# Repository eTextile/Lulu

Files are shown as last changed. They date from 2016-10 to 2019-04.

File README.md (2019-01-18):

# Lulu-star

**Programming light into textile**

Lulu is a hardware solution that interfaces between an LED light source, an optic fiber strand or bundle and soft circuit connections.
Providing an optic fiber connection toolset and workflow for E-Textiles and Wearable Technology applications.

This project is still in a beta phase, where drastic changes may occur and backwards compatibility is not guaranteed until the final release.

Lulu-star
Lulu-star
Lulu-star

### About The project
Lulu is providing a simple, reliable toolset for people who want to use side glow optical fibers in their eTextile and wearable projects.
Use of light in textile and fashion design is becoming more and more common and many schools started to teach this subject as a part of their textile design curriculum.
Optic fibers could be embedded in textiles as embroidery, in weaving, knitting and knotting process and many textile designs have been realized in recent years.
But often the designers lack the toolset for connecting the light sources with the embedded optic fibers, resulting in re-purposing bulky connectors and technology and hiding them behind the textiles.
Currently, each designer has to come up with their own re-purposed or DIY solution.
Lulu is a connector that optimizes the efficiency of the connection between the light source and the optical fibers to get a strong illumination.
Instead of struggling to solve the light source and connection problem, the designer can concentrate on the aesthetic and textile making process issues.

### Lulu branches
- **Lulu-star** (master)
  - This branch provide a tiny PCB with a 200mA LED, PWM driver and optic fiber connector.
- **Lulu-daisy**
  - This branch provide a tiny PCB with an addressable LED (WS2812-mini, Dotstar, etc) and an optic fiber connector.
- **Lulu-MCU**
  - This branch provide a tiny PCB with a built in MCU (ATTiny10) that allow one-wire communication bus system.
- **Lulu**
  - This branch provides a motherboard (Lucette) that drives up to 16 Lulus that each only contain a power LED and an optic fiber connector.

###  Branche naming conventions / Version Control
- First number is used to specify Lulu type
  - 2.0.0 -> Lulu-star
  - 3.0.0 -> Lulu-daisy
  - 4.0.0 -> Lulu-MCU
- Second number is used to specify the PCB shape
  - 2.0.0 -> Lulu-star/Circle (this is the most common eTextile PCB shape but doesn't fit the zero waste).
  - 2.1.0 -> Lulu-star/Triangle (this shape fit the three wire connectors and zero waste panelization process).
  - 2.2.0 -> Lulu-star/Blob...
- Third number is used to specify the iteration
  - 2.1.1 -> [Made with Upverter an online PCB router software.](https://upverter.com/DataPaulette/08fe1452dfd87b08/Lulu-star_211/ "Made with Upvetrter, online PCB router software") 
  - 2.1.2 -> [Made with KiCad 5.0.0](./kicad_Lulu_star/Lulu_star_212/ "Made with KiCad 5.0.0") 

### Development tools & DOCs
 * **Web page**: [http://lulu.eTextile.org](http://lulu.eTextile.org "The project Web page")
 * **Kobakant web page**: [http://www.kobakant.at/KOBA/lulu-developments](http://www.kobakant.at/KOBA/lulu-developments "Kobakant project Web page")
 * **Repository**: [https://github.com/eTextile/Lulu/tree/master](https://github.com/eTextile/Lulu/tree/master "The project repository")
 * **License**: [CC-BY-SA](https://github.com/eTextile/Lulu/blob/master/LICENSE "See the Lulu license project")
 * **Video**: [Lulu project by Hannah](https://www.youtube.com/watch?v=drAoLd_eUWk "Lulu project Introduction")
 * **Video**: [Lulu project by Maurin](https://vimeo.com/249171264 "eTextile bus solution")
 * **Mail**: [lulu@etextile.org](mailto:lulu@etextile.org "eMail us")
 * **IRC**: [Riot](https://vector.im/develop/#/room/#lulu:matrix.org "Join us on the chat to collaborate in the development")
 * **Pictures**: [Flickr](https://www.flickr.com/groups/3908991@N25/ "Share your Lulu pictures project")

```
*Editable / multipurpose
                                 Forkable
             Low|-------------------|//////////////////////////////////////////|High

*Production method
                            Crafter
             DIY|--------------|///////////////////////////////////////////////|Industry

*Price
                                             6€
             Low|////////////////////////////|---------------------------------|High

*Skils level of users
                                                 Crafter
        Beginers|///////////////////////////////////|--------------------------|Expert

*Level of integration
               PCB                   PCB++
        Standard|/////////////////////|----------------------------------------|Non standard (e-textile)

*Level of complexity
                                                                          Lulu + LED-driver
                                                           Lulu + LED-driver   + MCU
              Lulu               Lulu + LED-driver         Lulu + MCU          + Battery & charger
             Low|/////////////////////| ------------------------|--------------|High

*Robusness / Life span (Connectors, testing, evaluating)
         Fragile|/////////////////////| ------------------------|--------------|Stong

*Project ethics
                                                         Sparkfun
              DIY  Crow-fonded  Localy                   Adafruit  Seed      China
           High|--------|--------|//////////////////////////|--------|---------|low

*Optic Fibers
               20cm    1m     2m
           Schot|------|///////|-----------------------------------------------|Long

*Tech
                                                OpenPCB                  Open-cylycium
          Closed|-------------------------|////////|///////|-------------------|Free & Full Open

*Liscence
          Closed|--------------------------------------------------------------|Free & Open

*Peripherals
     Free (Open)|-------------------|-----------------------|------------------|Closed

```

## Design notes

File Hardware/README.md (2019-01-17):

# Lulu-star / Hardware
**Programming light into textile**

# Lulu-star

Lulu_212_KiCad-3D_recto
Lulu_212_KiCad-3D_verso

## Hardware design
This branch of the Lulu project is using a 200mA power LED with current current circuitry.
As the project is focussing on embedded electronics we chosed an high power OSRAM OSLON LED that can have a good autonomy with a small Lypo battry (1000 mA).
As this kind of LED is seeking 200 mA (5 hour of autonomy with a 1000 mA battery).
The LED is also providing a narrow angle (60°) to focus the light in the optic fiber tranche.
	See datasheet: https://github.com/eTextile/Lulu/blob/master/Hardware/DOCs/LY_CN5M.pdf
The brass tube connector have been selected to fit the outer diameter of the LED package.
The PCB triangle shape have been selected to fit the zero waste in the production process.
All the components are SMD package to reduce the size and price of th PCB.
We have been experiencing a new way to hand solder the LED on the edge of the PCB but it is still not so handy to do it manually.
Custom tooling will be designed and tested to help in that soldering process.

## Release notes
### Lulu-star 2.1.2
- Initial release
### Lulu-star 2.1.3
- Clearance of top and bottom ground plane have been increased to avoid shortcuts due to the board edge cut to close.
- Resistor R2 have been flipped and the brass tube soldering pad moved.
- Updated brass tube soldering pad to be connected to the ground plane with thermals.
- Increased size of sewing holes to : 2mm
- Increased size of eTextile connectors to : 1mm
- Increased board size by ... mm
- Reorganized eTextile connectors order, this is more convenient for many purposes.

## Lulu connecting
- [VCC] (+) 3.3 to 5 Voltes
- [GND] (-) GND
- [PWM] I/O PIN

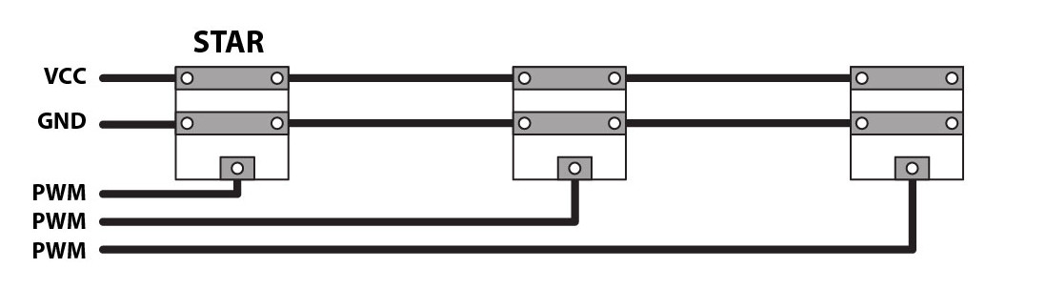
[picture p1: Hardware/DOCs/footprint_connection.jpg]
Footprint_connection


        +---+--------------+-------------------+-----
        |   |              |                   |
    + __|__ |              |                   |
    -  ___  |              |                   |
        |   |              |                   |
        +---|--------------|--+----------------|--+--
        |   |              |  |                |  |
        |   |              |  |                |  |
        |   |            __|__|__              |  |
       _|___|_           \ +  - /              |  |
      | +   - |           \    /               |  |
      |   M   |--- PWM --> \  /              __|__|__
      |   C   |             \/               \ +  - /
      |   U   |                               \    /
      |       |--- PWM ----------------------> \  /
      |_______|                                 \/

## Lulu-star Powering
The Lulu board must be powered with a voltage betwin 3.3V to 5V.
DO NOT USE 3V single coin battery - voltage is too low and it will not work for long.
Prefer the use of rechargeable Lipo battery with small Lipo charger.

## Lulu-star Arduino programming
Easy to programmed, Lulu-star is using the Arduino IDE standard functions - no library required.

    digitalWrite(LED_PIN, state);
    analogWrite(LED_PIN, val);

## Lulu-star LED driver built-in
### Constant current source circuitry

**References**
- https://learn.adafruit.com/pixie-3-watt-smart-chainable-led-pixels/design
- http://www.instructables.com/id/Power-LED-s---simplest-light-with-constant-current/
- https://scienceprog.com/building-simple-constant-current-power-led-driver/
- http://www.pcbheaven.com/userpages/LED_driving_and_controlling_methods/?topic=worklog&p=3

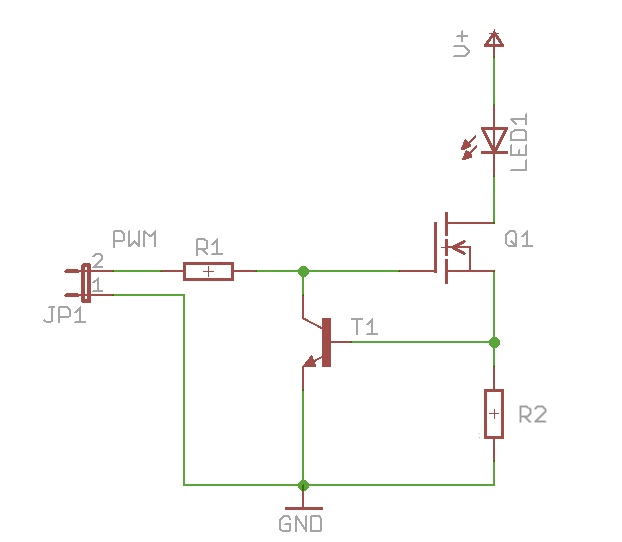
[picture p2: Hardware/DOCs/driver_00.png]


### Circuit part list
| Designator | MPN | Package | Price per unit | Weblink |
| --- | --- | ---|--- |---|
| Power LED / OSRAM 200mA | LY CN5M | | 0.65 $ | [LY-CN5M](https://fr.aliexpress.com/item/OSRAM-OSLON-SX-High-Power-LED-0-5W-3030-Yellow-LY-CN5M/32865040281.html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) |
| Q1 - large N-channel MOSFET | IRLML2060TRPBF | SOT-23 | 0,126 € | [IRLML2060TRPBF](https://www.digikey.com/product-detail/en/infineon-technologies/IRLML2060TRPBF/IRLML2060TRPBFCT-ND/2271917) |
| T1 - small NPN transistor | MMBT2222A | SOT-23 | 0,0412 € | [MMBT2222A](https://www.digikey.com/product-detail/en/diodes-incorporated/MMBT2222A-7-F/MMBT2222A-FDICT-ND/815723) |
| R1 - 47k-ohm resistor | RT0603DRD0747KL | 0603 | 0,0147 € | [R-47k-ohm ](https://www.digikey.com/product-detail/en/yageo/RT0603DRD0747KL/311-47KDCT-ND/1035828) |
| R2 - current set resistor - 2.7 ohms 1/4 watt | | 1206 | 0,0246 € | [R-2.7-ohm](https://fr.farnell.com/walsin/wr12w2r70ftl/resist-couche-epaisse-2-7r-1-0/dp/2668305) |
| R3 - 10k pull-down resistor | RT0603DRD0710KL | 0603 | 0, € | [R-10k-ohm](https://www.digikey.com/product-detail/en/yageo/RT0603DRD0710KL/311-10KDCT-ND/1035680) |

**R2** is used to set the current limit and this doesn't depends on the voltage supply VDD.
**Q1** is used as a variable resistor. **Q1** starts out turned on by **R1**.
**T1** is used as an over-current sensing switch, and **R2** is the "sense resistor" that triggers **T1** when too much current is flowing.
The main current flow is through the LED's, through **Q1**, and through **R2**.
When too much current flows through **R2**, **T1** will start to turn on, which starts turning off **Q1**. Turning off **Q1** reduces the current through the LED's and **R2**.
So we've created a **feedback loop**, which continuously tracks the current and keeps it exactly at the set point at all times.
The NPN transistors **T1** have a specified 0.6V drop between base and emitter when on.
This means the voltage across their respective shunt resistors **R2** will always be 0.6V.
According to Ohm’s law, this means that the current through them will be '0.6 V / 2.7 Ohm', or about 222mA.

## PCB manufacturing characteristics
  - Base Material : FR-4 TG13
  - No. of Layers : 2 layers
  - PCB Thickness : 1 mm
  - PCB Color : Yelow
  - Surface Finish : HASL
  - Minimum Solder Mask Dam : 0.4 mm
  - Copper Weight : 1oz (35 µm)
    - For 300 mA we nead 0.15mm copper traces (https://www.4pcb.com/trace-width-calculator.html)
  - Minimum Drill Hole Size : 0.3 mm
  - Trace Width / Spacing : 5/5 mil
  - Blind or Buried Vias : NO
  - Plated Half-holes / Castellated Holes : YES
  - Impedance Control : NO

### Extra Part list
| Part | REF | Price per unit | Weblink |
| --- | --- | ---|--- |
| Brass tube | 2 mm Hole 5-10 mm Length | | |
| JTE connector | 1.5 / 8 mm | | |
| Optical fibres PMMA | 0.25 mm x 35 pce | | |
| Optical fibres TPU | 1.5, 2, 3 mm | | |
| Optical fibres tube + core | | | [www.leds-and-more.de](https://www.leds-and-more.de/catalog/15mm-lwl-lichtwellenleiter-lichtleiter-seitlich-leuchtend-p-1937.html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) |

## TODO
- [ ] Find 0.5W side LEDs
- [ ] Chose between a small single LED driver & Constant current source circuitry
- [ ] Optimize the power LED heat dissipation
- [ ] Identifying distributors in Europe

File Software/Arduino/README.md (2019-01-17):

# Lulu-star

### Programming light into textile
This file is listing a group of examples that can be a starting point to make a project out of the Lulu-star hardware.

Microcontroleurs such as Adafruit Gemma, Trinketor or DIGISPERK are cool components to get a nice eTextile integration.

## DIGISPARK specifications

** UNDER MACKINTOSH YOU WILL NEED A USB HUB TO PROGRAM THE DIGISPARK BOARD! **
- Instaling Digispark support for Arduino
  - Add this link to the Arduino Préférences : http://digistump.com/package_digistump_index.json
  - Look for Digispark into the Arduino bord manager

    Digispark digital I/O PINs
    - Pin 0 → I2C SDA, PWM (LED_BUILTIND on Model B)
    - Pin 1 → PWM (LED_BUILTIN on Model A)
    - Pin 2 → I2C SCK, Analog
    - Pin 3 → Analog In (also used for USB+ when USB is in use)
    - Pin 4 → PWM, Analog (also used for USB- when USB is in use)
    - Pin 5 → Analog In

## Adafruit Gemma specifications

- Instaling Gemma support for Arduino
  - Add this link to the Arduino Préférences : https://adafruit.github.io/arduino-board-index/package_adafruit_index.json
  - Look for Gemma into the Arduino bord manager

** THE SKETCH UPLOADING PROCESS IS NOT AS STANDARD ARDUINO BOARD **
...

#### Lulu_blink
Blinking a single lulu board

#### Lulu_fade
Fading a single lulu board (FIXME)

#### Lulu_fade_with_sensor
Fading the Lulu in combination with a light sensor (TODO)

#### Lulu_...

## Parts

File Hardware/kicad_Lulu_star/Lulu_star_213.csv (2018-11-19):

Designator | MPN | Qty | Link
R3 | RT0603DRD0710KL | 1 | https://www.digikey.com/product-detail/en/yageo/RT0603DRD0710KL/311-10KDCT-ND/1035680
T1 | MMBT2222A | 1 | https://www.digikey.com/product-detail/en/diodes-incorporated/MMBT2222A-7-F/MMBT2222A-FDICT-ND/815723
Q1 | IRLML2060TRPBF | 1 | https://www.digikey.com/product-detail/en/infineon-technologies/IRLML2060TRPBF/IRLML2060TRPBFCT-ND/2271917
R1 | RT0603DRD0747KL | 1 | https://www.digikey.com/product-detail/en/yageo/RT0603DRD0747KL/311-47KDCT-ND/1035828

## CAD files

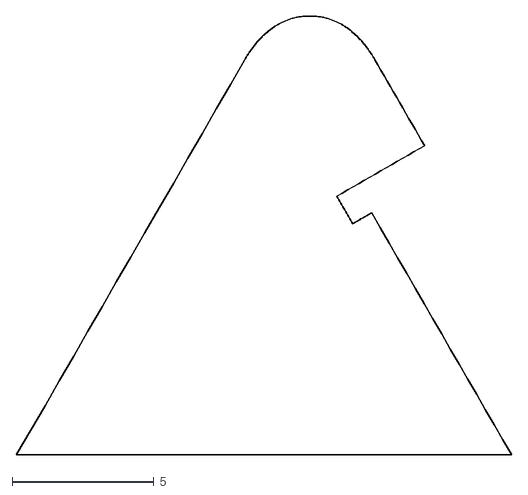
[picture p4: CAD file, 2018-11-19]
Hardware/kicad_Lulu_star/edge_path/Lulu_PCB_path_03.dxf
17.5 x 15.5

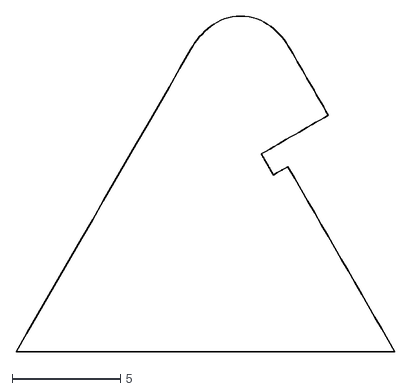
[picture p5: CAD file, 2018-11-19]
Hardware/kicad_Lulu_star/edge_path/Lulu_PCB_path_02.dxf
17.5 x 15.5

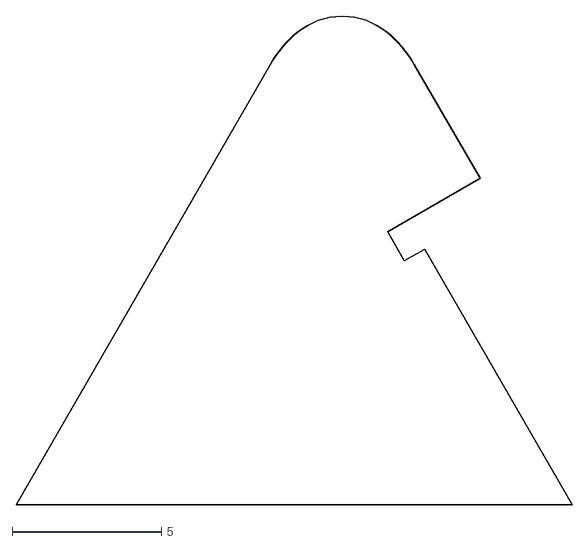
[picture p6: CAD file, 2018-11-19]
Hardware/kicad_Lulu_star/edge_path/Lulu_PCB_path_04.dxf
18.6 x 16.3

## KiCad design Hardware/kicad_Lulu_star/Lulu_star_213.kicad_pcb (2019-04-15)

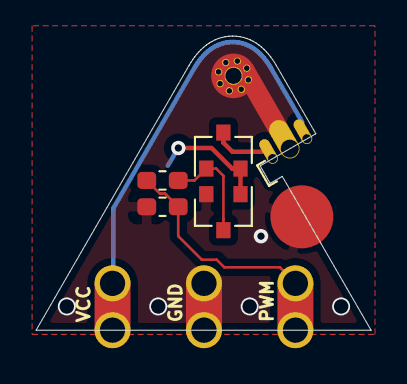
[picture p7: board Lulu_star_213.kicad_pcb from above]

Board: 2 copper layers, 18.6 x 16.3 mm, 9 parts (1 on the bottom side), 6 nets.

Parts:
J1: Conn_01x03_Female; Lulu_plug_3_spaced
LED1: LED_PAD; Lulu_side_LED
P1, P1#2: Soldering_pad; Lulu_brass_tube_pad
Q1: Q_NMOS_GSD; SOT-23
R1: 47K; R_0603_1608Metric_Pad1.05x0.95mm_HandSolder
R2: 2.7 Ohm; R_1206_3216Metric_Pad1.42x1.75mm_HandSolder
R3: 10K; R_0603_1608Metric_Pad1.05x0.95mm_HandSolder
T1: Q_NPN_BEC; SOT-23

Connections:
+3V3: J1.1, LED1.2
/PWM: J1.3, R1.2, R3.1
GND: J1.2, LED1.3, R2.2, R3.2, T1.2
unnamed: LED1.1, Q1.3
unnamed: Q1.1, R1.1, T1.3
unnamed: Q1.2, R2.1, T1.1

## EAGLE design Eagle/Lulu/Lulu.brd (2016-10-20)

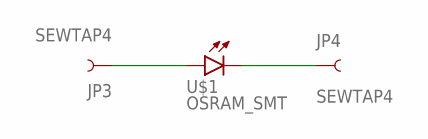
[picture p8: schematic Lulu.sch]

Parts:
JP3, JP4: SEWTAP4; PETAL-SMALL
U$1: OSRAM_SMT; OSLON

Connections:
unnamed: JP3.1, U$1.A
unnamed: JP4.1, U$1.C

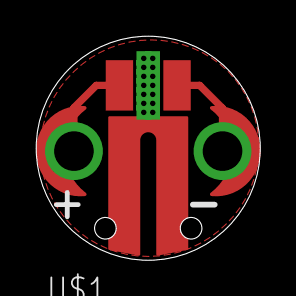
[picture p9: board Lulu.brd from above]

Board: 2 copper layers, 12.4 x 12.4 mm, 3 parts (0 on the bottom side), 2 nets.

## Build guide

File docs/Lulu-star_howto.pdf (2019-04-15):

# Lulu-star V2.2.1

## Exploring light through textile

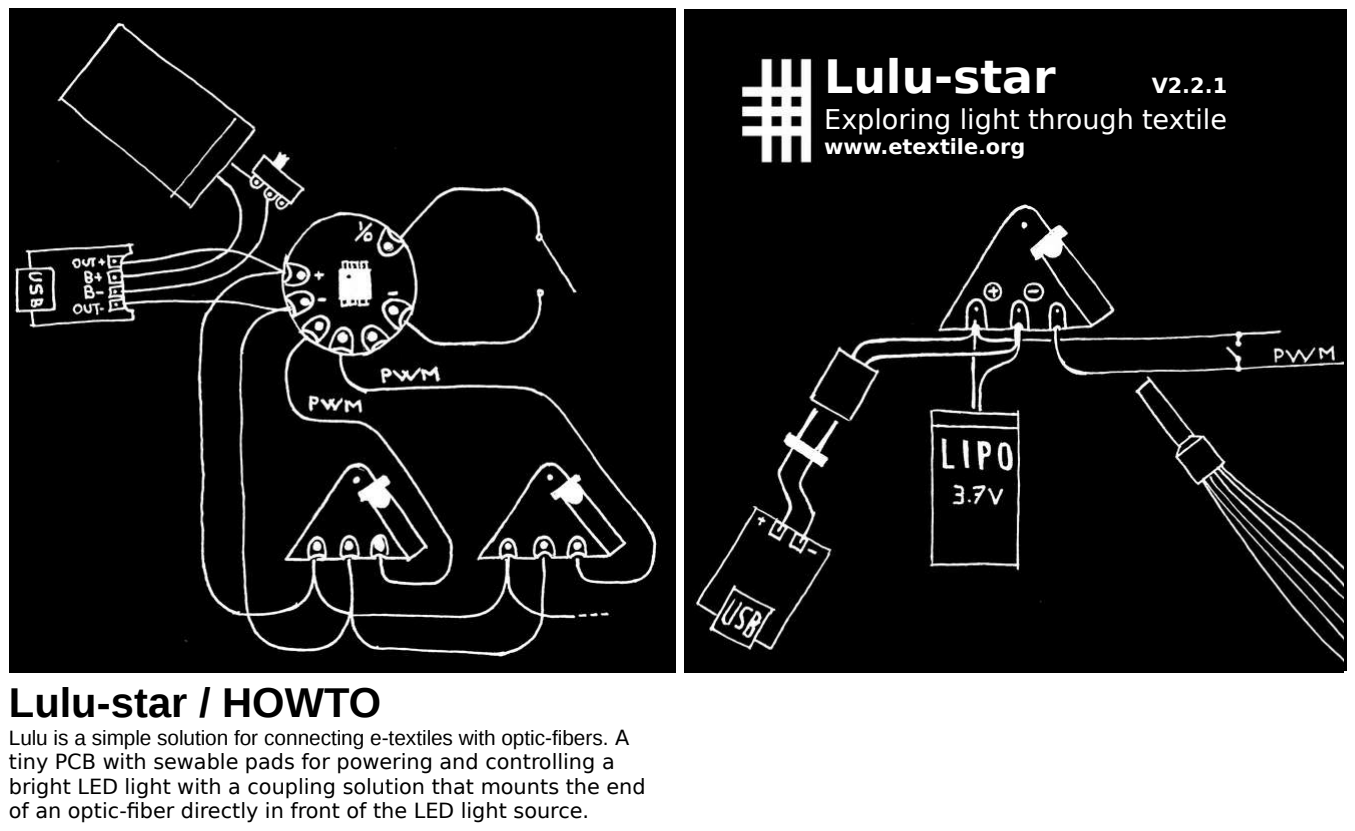
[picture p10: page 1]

www.etextile.org

# Lulu-star / HOWTO

Lulu is a simple solution for connecting e-textiles with optic-fibers. A tiny PCB with sewable pads for powering and controlling a bright LED light with a coupling solution that mounts the end of an optic-fiber directly in front of the LED light source.

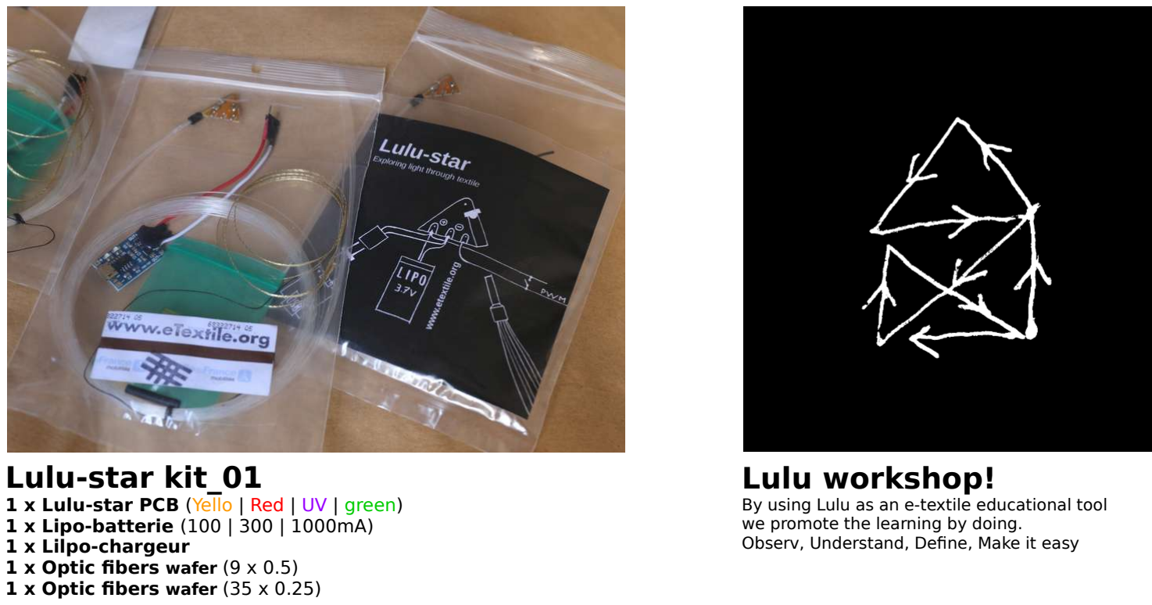
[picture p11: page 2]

L

## ulu-s

t

a

r

V

2.2.1

# Lulu workshop!

By using Lulu as an e-textile educational tool we promote the learning by doing.
Observ, Understand, Define, Make it easy

# Lulu-star kit_01

### 1 x Lulu-star PCB (Yello | Red | UV | green) 1 x Lipo-batterie (100 | 300 | 1000mA) 1 x Lilpo-chargeur 1 x Optic fibers wafer (9 x 0.5) 1 x Optic fibers wafer (35 x 0.25)

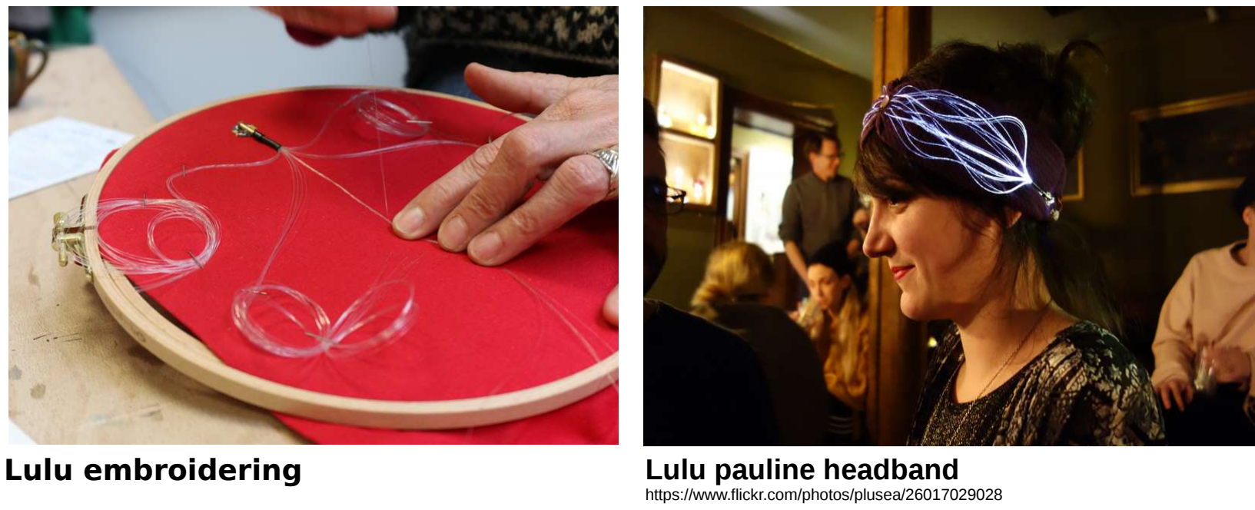
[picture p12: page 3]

L

## ulu-s

t

a

r

V

2.2.1

Lulu embroidering | Lulu pauline headband https://www.flickr.com/photos/plusea/26017029028

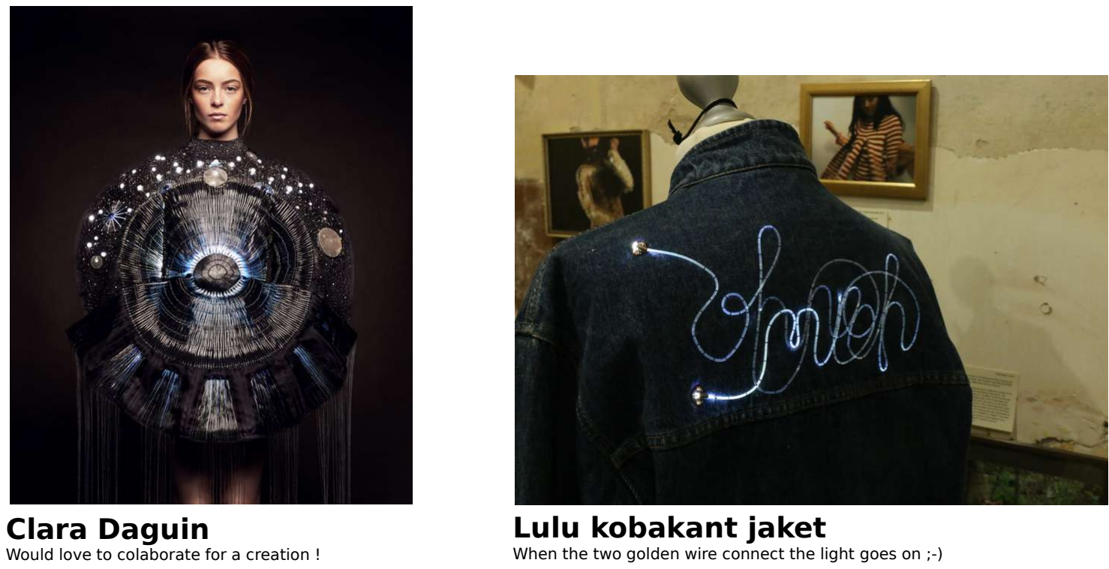
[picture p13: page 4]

L

## ulu-s

t

a

r

V

2.2.1

# Lulu kobakant jaket

When the two golden wire connect the light goes on ;-)

# Clara Daguin

Would love to colaborate for a creation !

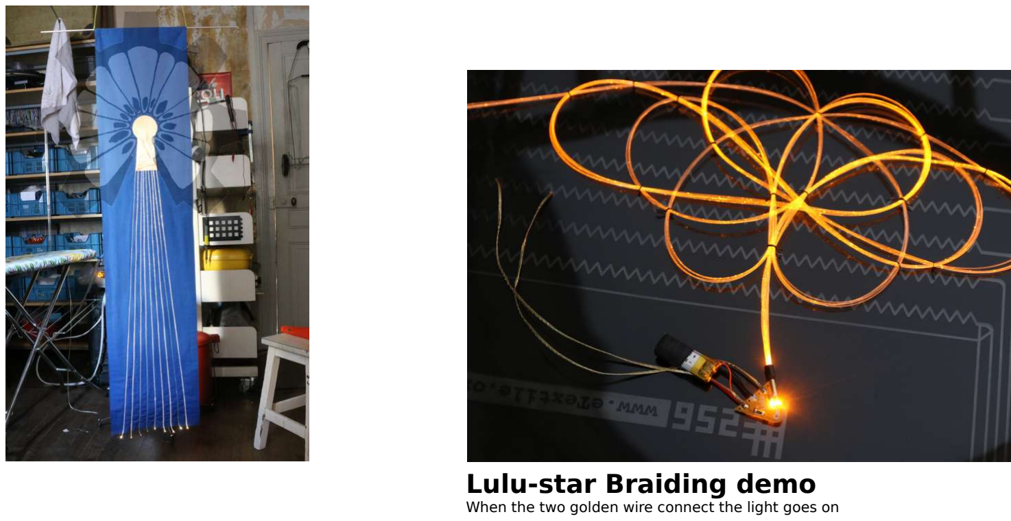
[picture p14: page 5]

L

## ulu-s

t

a

r

V

2.2.1

# Lulu-star Braiding demo

When the two golden wire connect the light goes on

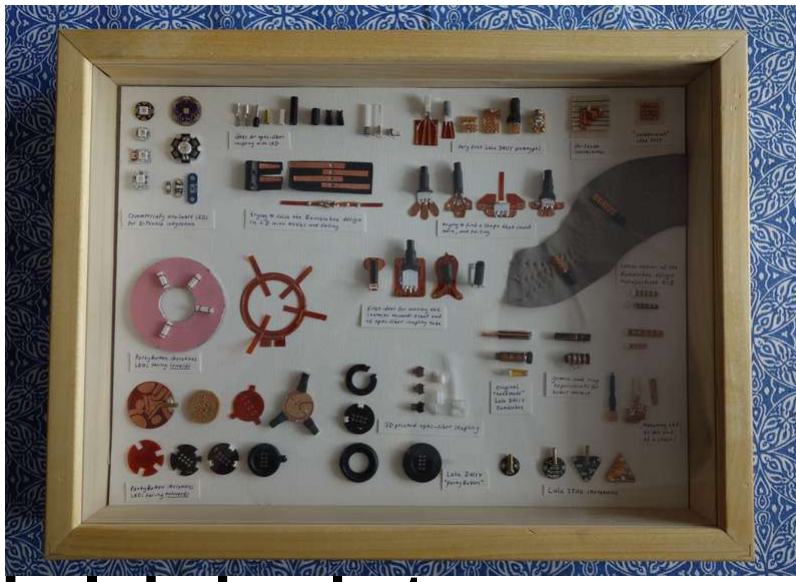
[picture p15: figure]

# Lulu’s backstage

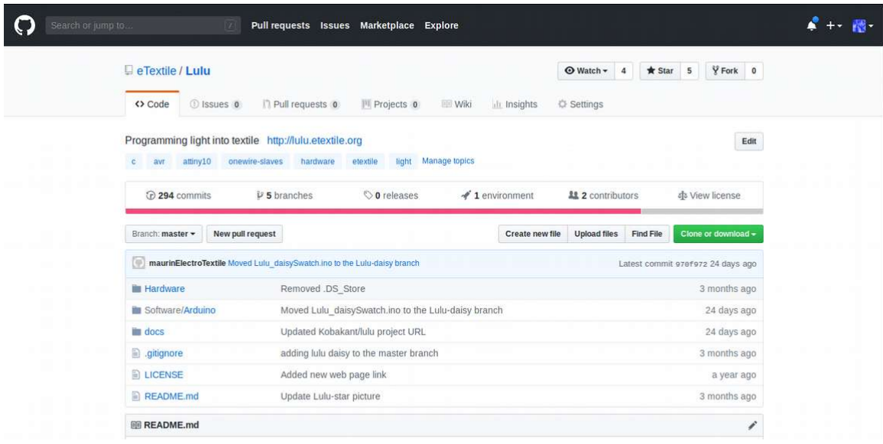
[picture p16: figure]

# Open hardware & open software

The project source code is hosted on Github repository Users can fork the design to adapt to their needs
and collaborate in the development.

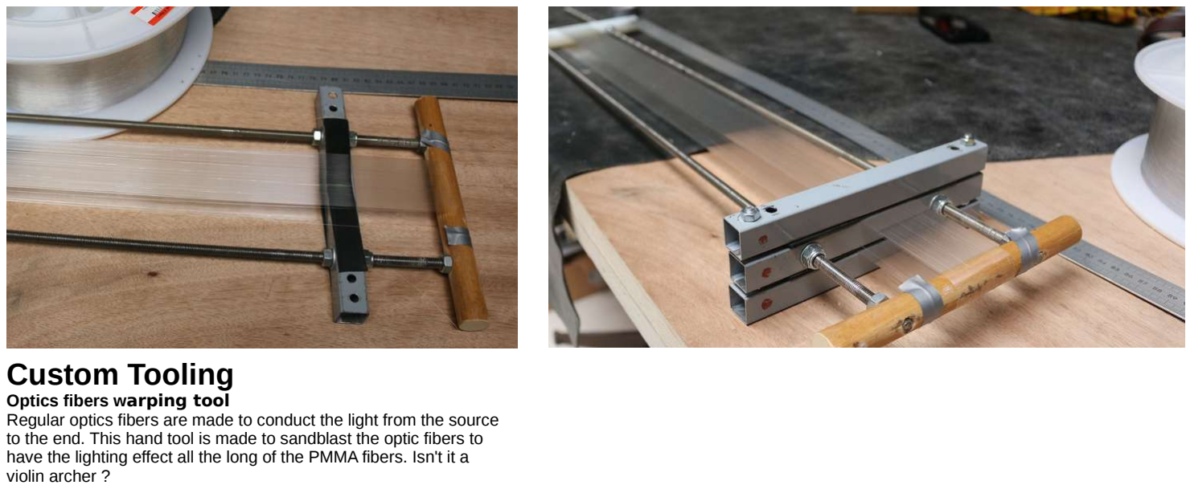
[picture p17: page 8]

# Custom Tooling

Optics fibers warping tool
Regular optics fibers are made to conduct the light from the source to the end. This hand tool is made to sandblast the optic fibers to have the lighting effect all the long of the PMMA fibers. Isn't it a violin archer ?

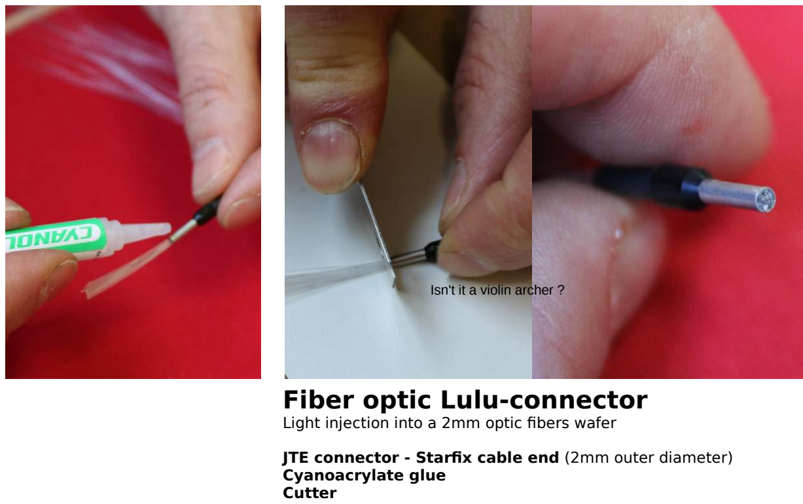
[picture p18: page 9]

# Fiber optic Lulu-connector

Light injection into a 2mm optic fibers wafer

JTE connector - Starfix cable end (2mm outer diameter) Cyanoacrylate glue
Cutter

Isn't it a violin archer ?

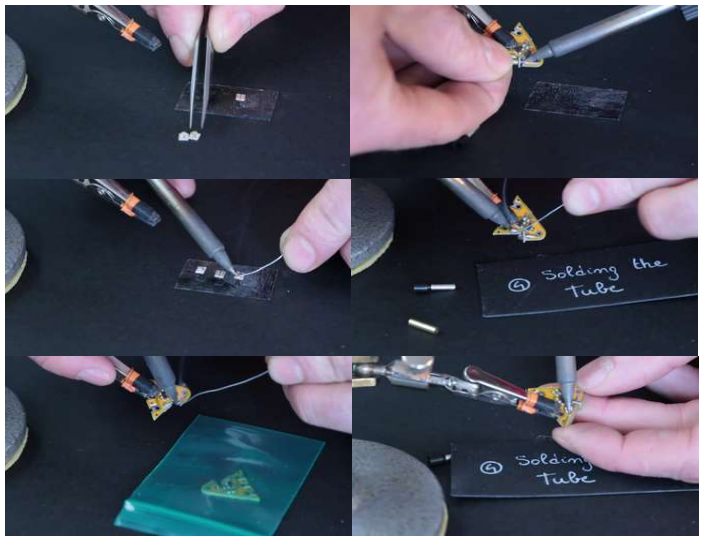
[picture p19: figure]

1/ LED tining
2/ PCB thermal pad tining
3/ LED Soldering
4/ Brass tube soldering (This can be optimized in the next Lulu-star version) 5/(R2) Resistor soldering (This curent setup resistor could be pick and place for 200mA setup, can still be resolder for other setup)

LED osram
oslon | Ref | Current | Résistor
YELOW (https://fr.farnell.com/osram/lhcp7p-2t3t-1/led-oslon-ssl-hyper-rouge-80/dp/2115537?ost=2115537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) | farnell.com /osram (https://fr.farnell.com/osram-opto-semiconductors/lacn5m-fbgb-24-1/led-oslon-sx-ambre/dp/1826990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) | 200 mA | 2.7 Ohm
RED (https://fr.farnell.com/osram/lhcp7p-2t3t-1/led-oslon-ssl-hyper-rouge-80/dp/2115537?ost=2115537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) | farnell.com /osram (https://fr.farnell.com/osram/lhcp7p-2t3t-1/led-oslon-ssl-hyper-rouge-80/dp/2115537?ost=2115537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) | 350 mA

GREEN

UV (https://fr.farnell.com/osram/lhcp7p-2t3t-1/led-oslon-ssl-hyper-rouge-80/dp/2115537?ost=2115537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)

# Lulu-star hand soldering

https://github.com/eTextile/Lulu/tree/master/Hardware Osram OSLON LED (200-350mA)
Brass tube (10mm long, 2mm inner diameter)
Current limit resistor R2 (Thick film 0.25W)

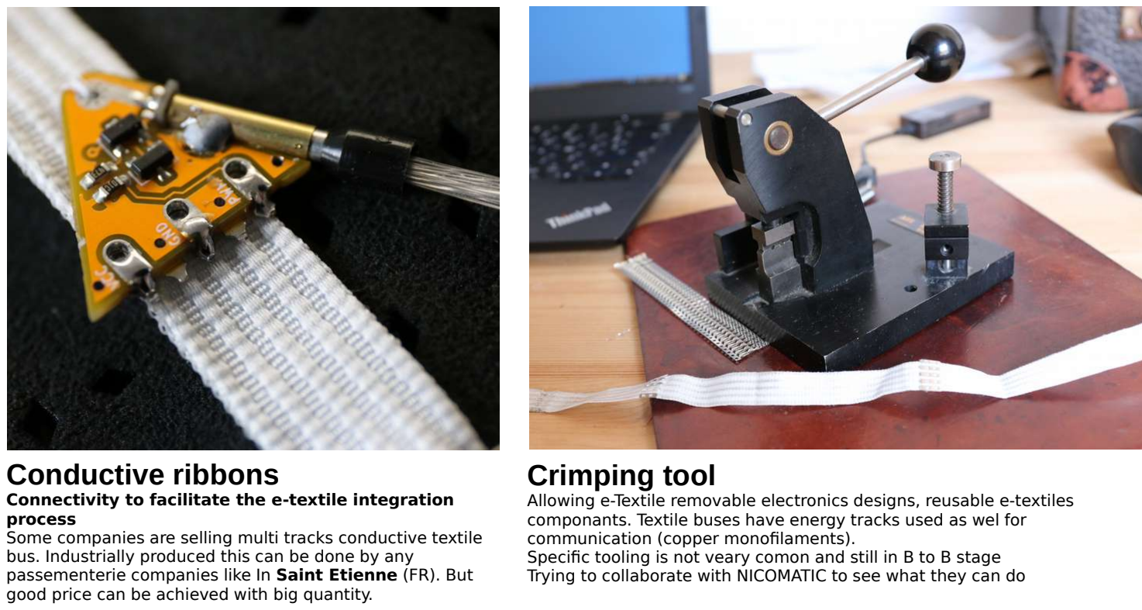
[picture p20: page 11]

# Crimping tool

Allowing e-Textile removable electronics designs, reusable e-textiles componants. Textile buses have energy tracks used as wel for communication (copper monofilaments).
Specific tooling is not veary comon and still in B to B stage
Trying to collaborate with NICOMATIC to see what they can do

# Conductive ribbons

Connectivity to facilitate the e-textile integration process
Some companies are selling multi tracks conductive textile bus. Industrially produced this can be done by any passementerie companies like In Saint Etienne (FR). But good price can be achieved with big quantity.

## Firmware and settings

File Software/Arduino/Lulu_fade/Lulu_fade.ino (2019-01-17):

/*
  Lulu - Programing light into textile

  Lulu-star / Arduino code / This sketch is an example that control a single Lulu.

  Lulu-star circuitry
     _________________________________
    |              |                  |
    |            __|__                |
    | +         |  +  |              / \
  __|__         |  M  |             / L \
   ---          |  C  |--- PWM --> /  U  \
    | -         |  U  |           /   L   \
    |           |__-__|          /____U____\
    |              |                  |
    |______________|__________________|

   (+) is 3.3 to 5V

*/
#include <elapsedMillis.h> // https://github.com/pfeerick/elapsedMillis

elapsedMillis timer;

const int PWM_PIN = 13; // This PIN is also connected to the Digispark Motherboard LED_BUILTIN.

void setup() {
  Serial.begin(9600);
  pinMode(PWM_PIN, OUTPUT);    // Set PIN as OUTPUT PIN
  digitalWrite(PWM_PIN, LOW);  // Set PIN LOW (GND)
}

void loop() {
  Serial.println(timer);
  // arg-0 the PWM pin
  // arg-1 the fade IN time
  // arg-1 the fade OUT time
  lulu_fade(13, 1000, 1000);
}

///////////////////////////////////// Fonction
// TODO adding timer as argument
void lulu_fade(uint8_t pwmPin, uint32_t fadeSpeedUp, uint32_t fadeSpeedDown) {
  static int pwmValue = 0;
  static int intervalUp = (int)(fadeSpeedUp / 255);
  static int intervalDown = (int)(fadeSpeedDown / 255);
  static boolean dir = true;

  // Fade In
  if (dir == true && timer > intervalUp) {
    timer = 0;
    analogWrite(pwmPin, pwmValue);
    pwmValue++;
    if (pwmValue >= 255) {
      dir = false;
    }
  }

  // Fade Out
  if (dir == false && timer > intervalDown) {
    timer = 0;
    analogWrite(pwmPin, pwmValue);
    pwmValue--;
    if (pwmValue <= 0) {
      dir = true;
    }
  }

}

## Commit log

2014-05-06 Update lucette_seq.ino
    Optimisation du protocole de communication entre la carte Lucette et un logiciel Pilote réalisé avec PureData. Pour contrôler une sortie de la carte Lucette il faut utiliser trois octets :
    le premier pour définir la LED à actualiser le second et le troisième pour définir la valeur 12 bits (0-4095) qui correspond à l'intensité de la LED.
2014-05-06 Update README.md
    Fonctions de la carte Lucette / fork du projet Arduino
2014-05-07 Create LEDs_seq
2014-05-17 Update Lucette_seq.ino
    Bug fix in ledUpdate();
2014-07-01 Update Lucette_seq.ino
    add ERROR Handling if a LED is diconnected.
2015-10-08 added eagle boards
    [LOGO.dxf, Lucette_LED.sch, Lucette_V05.brd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]
2016-10-19 Updated text
    Luce is the project, Lucette is the electronic board
2016-10-20 add Lulu PCB
    [Lulu.brd, Lulu.sch]
2016-10-20 clean up
    [LOGO.dxf, Lucette_V05.brd, Lucette_V05.sch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]
2016-10-20 re-organised README
    [Lulu.brd, Lulu.sch]
2016-10-20 clean README
    [LOGO.dxf, Partlist.ods]
2017-12-13 Initial commit from Lucette branche
    [LOGO.dxf, Lucette_V05.brd, Lucette_V05.sch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]
2017-12-13 Removed PureData Driver
2018-01-31 Adeed 1-wire github project ref
2018-02-04 Renamed foldes
    [Lulu_MCU.brd, Lulu_MCU.sch]
2018-02-04 Renamed files
    [Lulu_MCU.brd, Lulu_MCU.sch]
2018-02-05 Removed pictures and old files
    [Lulu_MCU.brd, Lulu_MCU.sch]
2018-02-26 Added web link of 1-wire lib for teensy
2018-02-26 Updated pull-up resistor value
2018-03-18 Added OpenJSCAD submodule
    [3d_sculpture-VernonBussler.stl, Amf_Cube.amf, CurveEdgeTest.amf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]
2018-03-18 Removed OpenJSCAD
    [3d_sculpture-VernonBussler.stl, Amf_Cube.amf, CurveEdgeTest.amf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]
2018-03-18 Added OpenJSCAD-web
    [3d_sculpture-VernonBussler.stl, Amf_Cube.amf, CurveEdgeTest.amf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]
2018-05-02 Removed Jscad
    [3d_sculpture-VernonBussler.stl, Amf_Cube.amf, CurveEdgeTest.amf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]
2018-05-09 Added new PCB design file link
2018-05-11 Added schematic drawing
2018-05-13 Added 3D openscad
    [Lulu-star.scad]
2018-05-14 Updated measurements
    [Lulu-star.scad]
2018-05-14 Minor change
    [Lulu-star.scad]
2018-06-03 Added driver circut picture
2018-06-04 Added connector
    [Lulu-star.scad]
2018-06-04 Added link to new PCB design
2018-06-12 Removed resistor value R1
2018-06-26 added PCB specs
2018-06-26 Added GERBER files
    [design_export.gbl, design_export.gbo, design_export.gbp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]
2018-08-03 Added LED Weblink
2018-08-21 Removed GERBER files will add new version after bug fix (T1 transistor was flipped)
    [design_export.gbl, design_export.gbo, design_export.gbp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]
2018-08-21 Added new LED datasheet
2018-08-21 Removed unused LED datasheet
2018-08-21 Added KiCad file
    [Lulu_star_211.kicad_pcb, Lulu_star_211.sch]
2018-08-21 Renamed folder
    [Lulu_star_212.kicad_pcb, Lulu_star_212.sch]
2018-08-21 Removed - kicad bad config
    [Lulu_star_211.kicad_pcb, Lulu_star_211.sch]
2018-08-21 Added circuit part list weblinks
2018-08-30 PCB in progress
    [Lulu_star_212.sch]
2018-08-30 Added PCB shape path
    [Lulu_212_PCB_path.dxf]
2018-08-30 Removed openScad 3D file -> 3D is now done with KiCad
    [Lulu-star.scad]
2018-08-30 Added application notes for PCB Thermal
2018-09-02 Added brass tube pad footprint
2018-09-02 Updated Lulu 212 path
    [Lulu_212_PCB_path.dxf]
2018-09-02 Routing in progress
    [Lulu_star_212.kicad_pcb, Lulu_star_212.sch]
2018-09-03 Moved file to Hardware/kicad_Lulu_star/Lulu_star_212/Library/
    [Lulu_212_PCB_path.dxf]
2018-09-03 Added PCB pin fonctions top & bottom
    [Lulu_star_212.kicad_pcb]
2018-09-04 Added some info for trace width calculation
2018-09-04 Routing done
    [Lulu_PCB_path.dxf, Lulu_star_212.kicad_pcb]
2018-09-04 Fixed 3D XYZ pos for KiCad import
2018-09-04 Updated Lulu footprints lib
2018-09-06 Added Pull down resistor on PWM pin
    [Lulu_star_212.kicad_pcb, Lulu_star_212.sch]
2018-09-12 Correct the thermal pad GND connection
    [Lulu_star_212.kicad_pcb]
2018-09-14 Updated ground plane
    [Lulu_star_212.kicad_pcb]
2018-09-18 Move down all components of the PCB
    [Lulu_star_212.kicad_pcb]
2018-09-18 Published GERBER
    [Lulu_star_212-B.Cu.gbr, Lulu_star_212-B.Mask.gbr, Lulu_star_212-B.Paste.gbr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]
2018-09-21 Added ziped GERBER files for production
2018-09-21 Updated clearance to 0.2
    [Lulu_star_212-B.Cu.gbr, Lulu_star_212-B.Mask.gbr, Lulu_star_212-B.Paste.gbr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]
2018-09-21 Added Software folder for Arduino examples
2018-09-22 Updated library path with relative position
    [Lulu_star_212.kicad_pcb]
2018-10-24 added hardware design & Lulu powering infos
2018-10-24 Added new Arduino examples
2018-10-24 Minor changes
    [Lulu_star_212.kicad_pcb]
2018-10-25 Added README to list the the Arduino examples
2018-11-19 Added Updated Lulu_star_213
    [Lulu_PCB_path_02.dxf, Lulu_PCB_path_03.dxf, Lulu_PCB_path_04.dxf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]
2018-11-19 Removed Lulu_star_212
    [Lulu_PCB_path.dxf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]
2018-11-19 In production
    [Lulu_star_213-B.Cu.gbr, Lulu_star_213-B.Mask.gbr, Lulu_star_213-B.Paste.gbr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]
2018-11-19 Added BOM
    [Lulu_star_213.csv]
2018-11-19 Updated BOM
2018-11-23 Updated schematics & picture
2019-01-08 adding lulu daisy to the master branch
    [LuluDaisyBumblebee.kicad_pcb, LuluDaisyBumblebee.sch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]
2019-01-17 Removed Lulu-dasy file to put it in it branch
    [LuluDaisyBumblebee.kicad_pcb, LuluDaisyBumblebee.sch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]
2019-11-18 Testing button
2019-11-18 Updated button
2019-11-18 Added new buttons

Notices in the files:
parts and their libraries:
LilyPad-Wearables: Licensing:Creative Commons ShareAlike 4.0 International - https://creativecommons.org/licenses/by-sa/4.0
